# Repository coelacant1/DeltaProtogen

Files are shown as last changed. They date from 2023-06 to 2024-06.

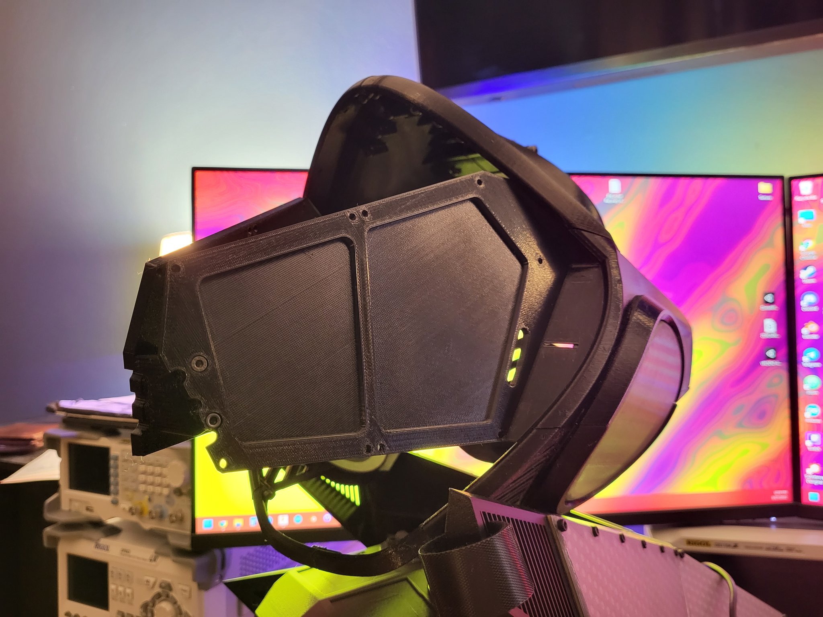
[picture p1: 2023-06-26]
Pictures/Print.jpg

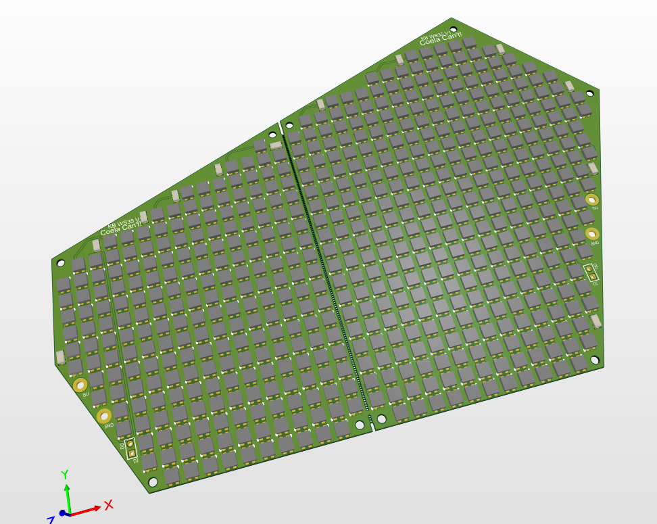
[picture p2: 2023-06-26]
Pictures/LEDBoard1.png

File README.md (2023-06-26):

# Delta Protogen

------------------------------------------
Coela Can't! Delta Protogen V1
Document Version: V1.0
------------------------------------------

Included are all of the STL files pre-oriented and ready for printing. But what about the visor? Well, two versions of the vacuum forming buck are included as well so you have the ability to make your own PETG visors. Don't forget that the 3D STEP and IGES CAD files are included, so if the design is not exactly what you want then you have the ability to modify and tweak it!

This design is built around printing on the Prusa i3 MK3s with build dimensions of X:250mm, Y:210mm, and Z:210mm. This design can be printed on smaller printers but may need to be modified or split requiring glue or the addition of screw mounts.

------------------------------------------
ASSEMBLY
------------------------------------------
Parts list:
Generic metric hardware kit (M3, M4, M5): https://www.amazon.com/Assortment-AETTL-Stainless-Assorted-Wrenches/dp/B098ND1GW8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
Threaded insert kit (M2, M3, M4, M5): https://www.amazon.com/DYWISHKEY-Knurled-Threaded-Embedment-Assortment/dp/B07MWBJB67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
M2 Screws (For Custom LED panels): https://www.amazon.com/uxcell-M2x6mm-Thread-Button-Socket/dp/B01B1OD9UQ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

The frame will bolt together with the use of M3 hardware, almost entirely with M3x8mm/10mm, ensure the screws are not protruding.
The top hinge is mounted with M5 threaded inserts and the hinge mechanism uses an M5 threaded insert and an M5x30mm bolt.
The rear latches are mounted with M3 threaded inserts and M3x10mm screws and use M5x8mm bolts with 20mm M5 grub screws.

------------------------------------------
VISOR
------------------------------------------
Print the V1 or V2 Buck
Make a vacuum former tutorial: https://www.youtube.com/watch?v=Gx66mS7U2vY
Material: Use 0.04" or 1.0mm PETG for proper thickness 

Magnetic mounts visor mount should be attached with a form of adhesive - double sided tape or epoxy - careful with super glue on the visor though! It will cloud it up. Use 6mmx2mm neodymium magnets and check the direction: https://www.amazon.com/FINDMAG-Refrigerator-Magnets-Premium-Whiteboard/dp/B075RZ82HP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

------------------------------------------
3D Printing
------------------------------------------
Recommended build dimensions: 250mmx210mmx210mm
Resolution: 0.2mm or higher quality
Supports: Depending on the overhang capabilities with your build plate, most require no support. The jaw requires a raft. Top head/forehead requires support.
Brim: Depending on your build surface a brim may be needed to bed adhesion
Material: PETG for frame and PVB for transparent side display covers - PLA can be used but it can melt if left in hot areas or in vehicles

------------------------------------------
Electronics for Custom LED Boards
------------------------------------------
Controller:
Teensy 4.0: https://www.pjrc.com/store/teensy40.html
OctoWS2811 LED Controller for the Teensy 4.0: https://www.pjrc.com/store/octo28_adaptor.html

Power: 
USB-C Decoy Trigger (USB-C to set voltage out): https://www.amazon.com/Type-C-USB-C-charge-trigger-detector/dp/B07T6LPP9W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
Buck Converter (5v-38V input to 5V output with at least 5 amps): https://www.amazon.com/Pololu-Step-Down-Voltage-Regulator-D24V90F5/dp/B01M9C9Q1E
Recommend 20W+ USB-C PD battery

Provide 5V directly to the LED boards from the buck converter and the signal lines from the OctoWS2811 controller.

------------------------------------------
Electronics for P3 Panels
------------------------------------------
Controller:
Teensy 4.0: https://www.pjrc.com/store/teensy40.html
SmartLED Shield for Teensy 4.0: https://www.crowdsupply.com/pixelmatix/smartled-shield-for-teensy-4

Power: 
USB-C Decoy Trigger (USB-C to set voltage out): https://www.amazon.com/Type-C-USB-C-charge-trigger-detector/dp/B07T6LPP9W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
Buck Converter (5v-38V input to 5V output with at least 5 amps): https://www.amazon.com/Pololu-Step-Down-Voltage-Regulator-D24V90F5/dp/B01M9C9Q1E
Recommend 20W+ USB-C PD battery

Provide 5V directly to the LED boards from the buck converter and the signal lines from the OctoWS2811 controller.

------------------------------------------
Software
------------------------------------------
Software for controlling the head can be found at: https://github.com/coelacant1/ProtoTracer
To use this with the custom LED boards, include the KaiborgV1D1Controller.h as the primary controller and pick the animation to display on the face from the animations class.
To use this with P3 HUB75 LED panels, include SmartMatrixHub75.h as the primary controller and pick the animation to display on the face from the animations class.

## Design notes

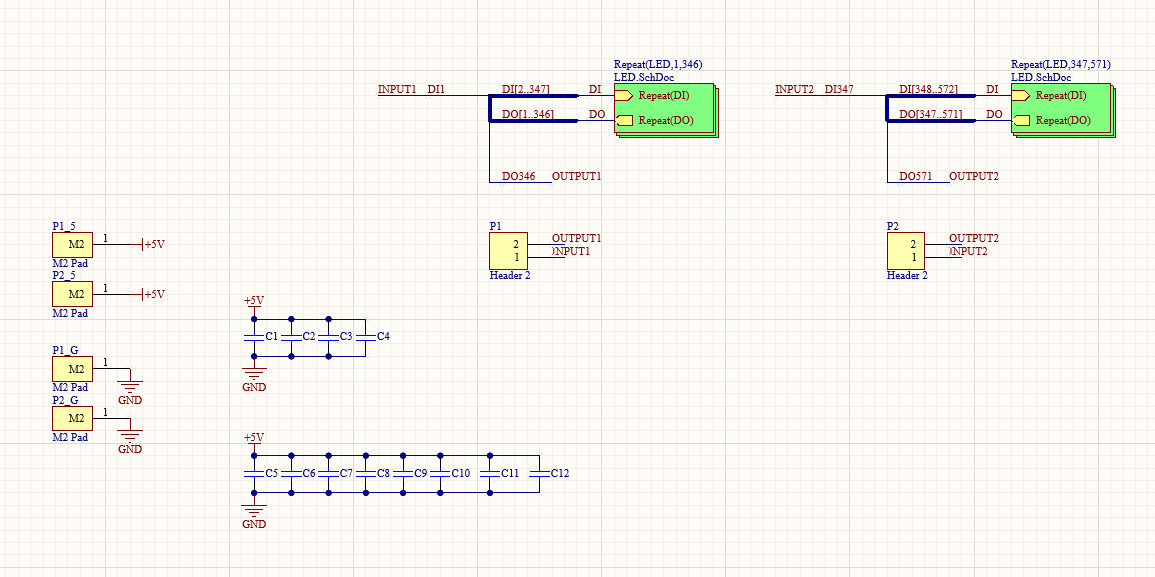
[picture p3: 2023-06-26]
Pictures/Schematic.png

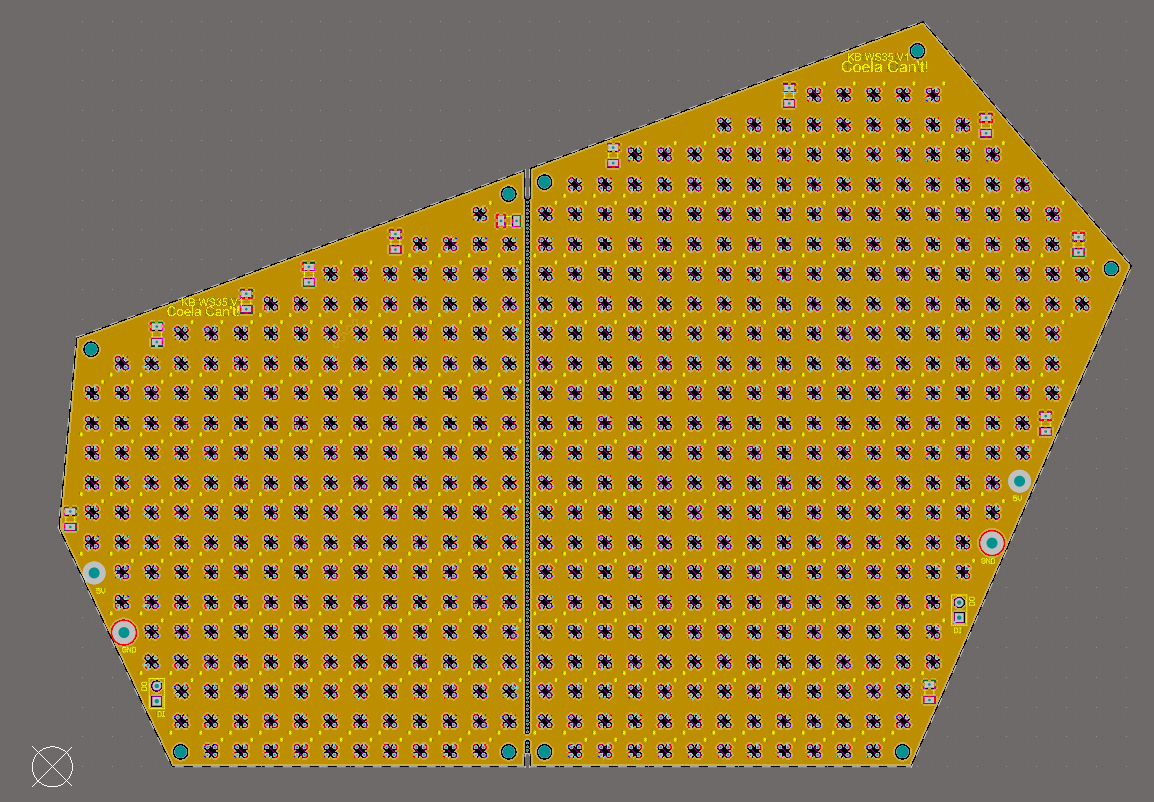
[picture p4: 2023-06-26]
Pictures/SignalLayer1.png

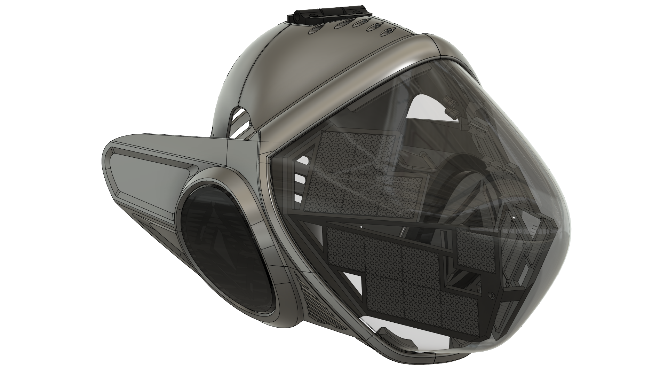
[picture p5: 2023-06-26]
Pictures/CoelaProtoSmoothV1_MAX7219.png

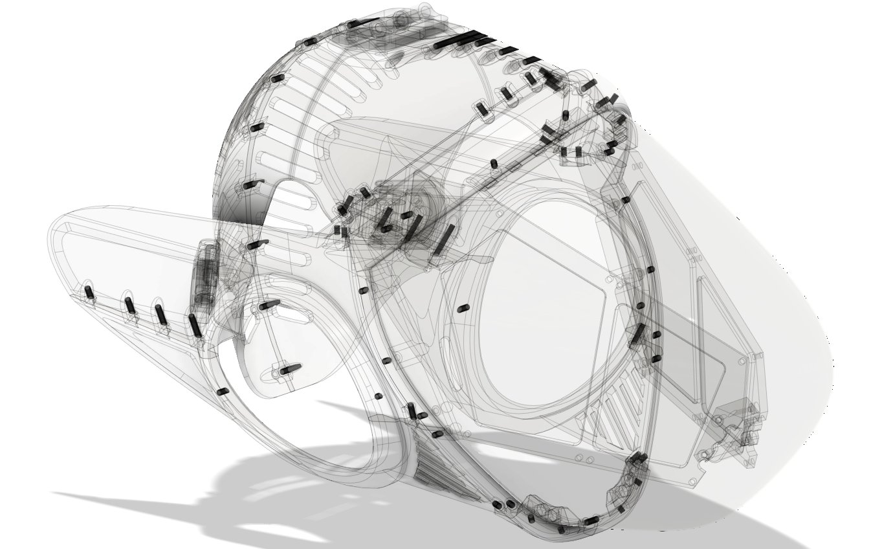
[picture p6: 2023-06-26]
Pictures/XRay.jpg

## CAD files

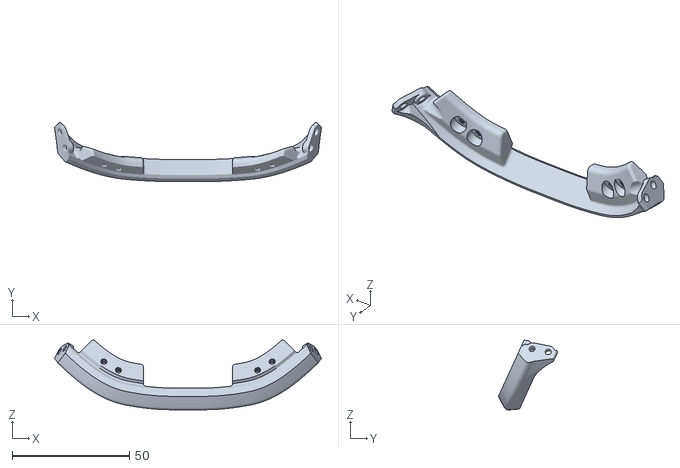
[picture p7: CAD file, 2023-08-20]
Frame/FullJaw.stl
113.7 x 25.2 x 29.7

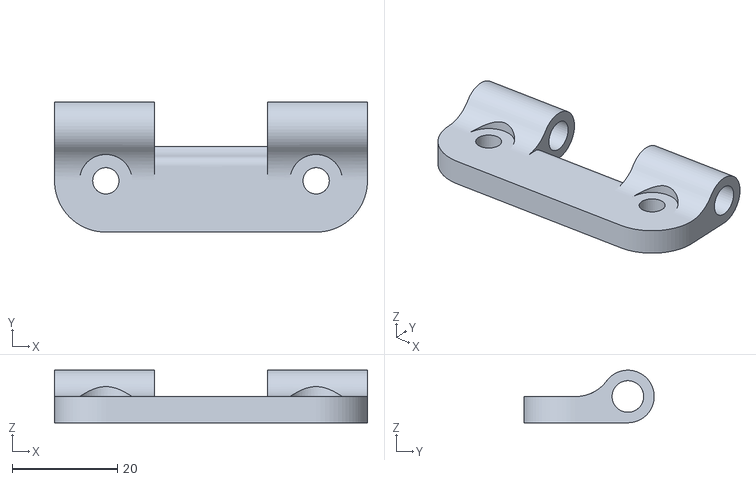
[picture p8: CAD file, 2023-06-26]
Hinge/FrontHinge_V1-0.stl
59.4 x 24.8 x 10.00

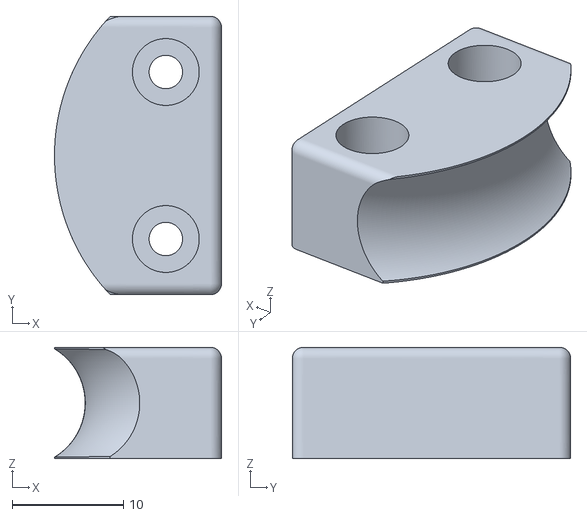
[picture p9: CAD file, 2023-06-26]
Latch/LatchLeftMount_V1-0.stl
15.0 x 25.0 x 10.0

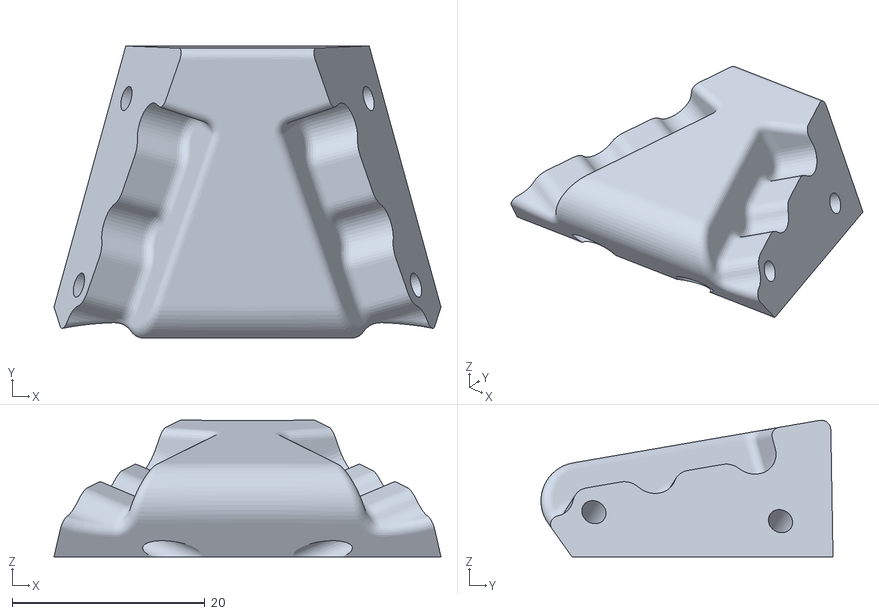
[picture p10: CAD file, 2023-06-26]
LED Mount KS W35/KSWS35_Connector_V1-0.stl
40.2 x 30.3 x 14.2

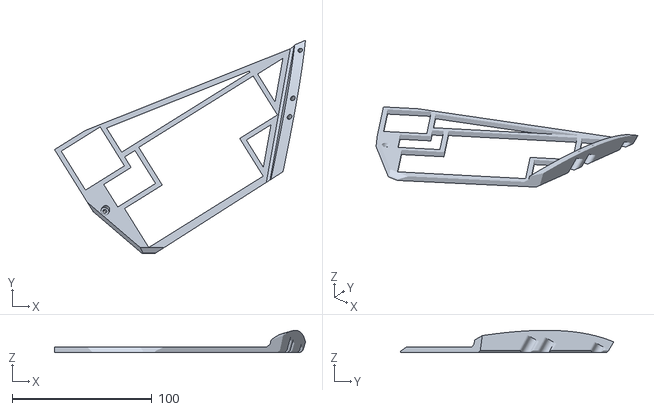
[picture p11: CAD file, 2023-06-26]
LED Mount MAX7219/MAX7219BotLeft_V1-0.stl
179.5 x 152.7 x 16.0

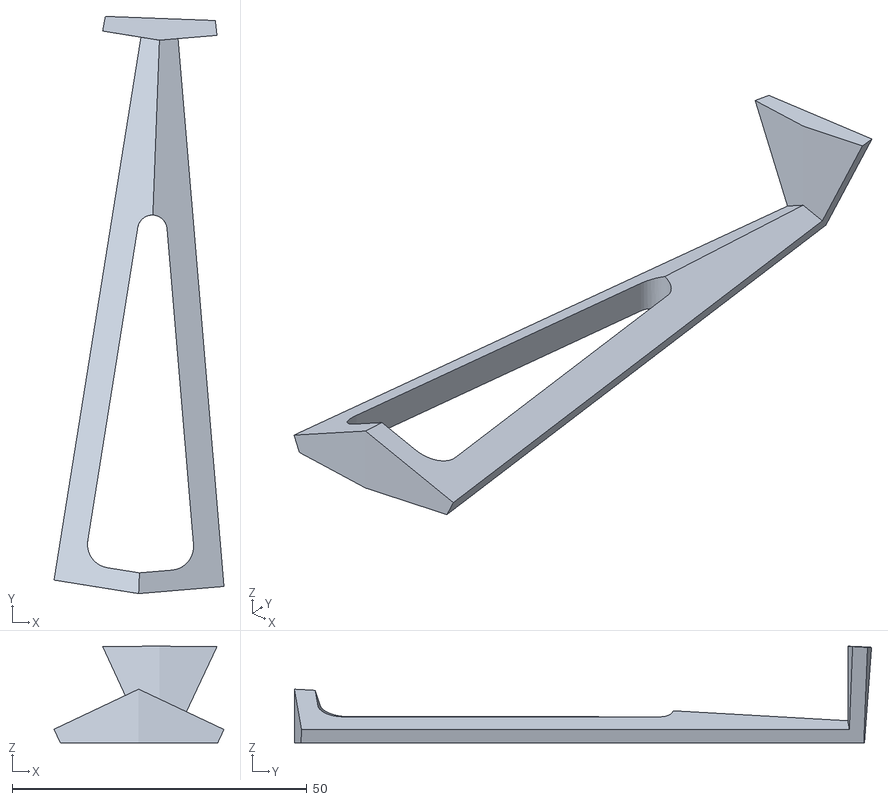
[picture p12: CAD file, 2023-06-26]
LED Mount P3 HUB75/P3Nose_V1-0.stl
28.9 x 98.0 x 16.4

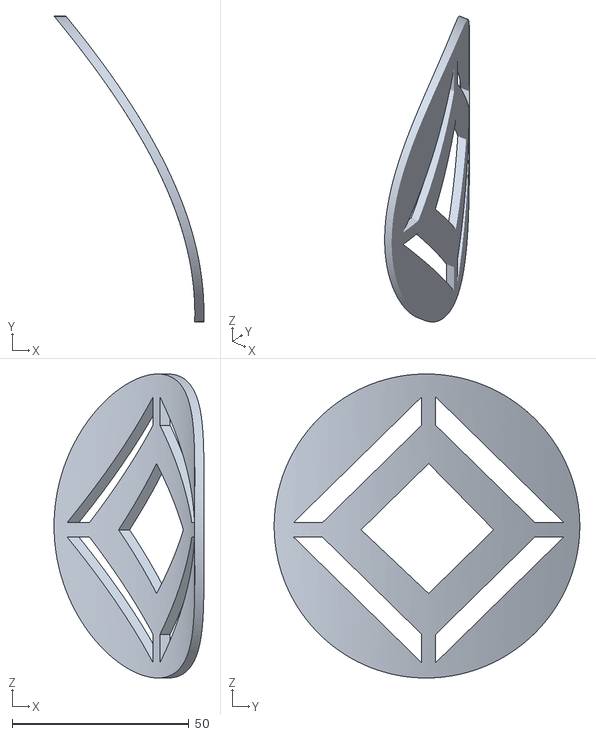
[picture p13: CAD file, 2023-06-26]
Side Displays/LeftPuckInnerSample_V1-0.stl
42.4 x 86.5 x 86.0

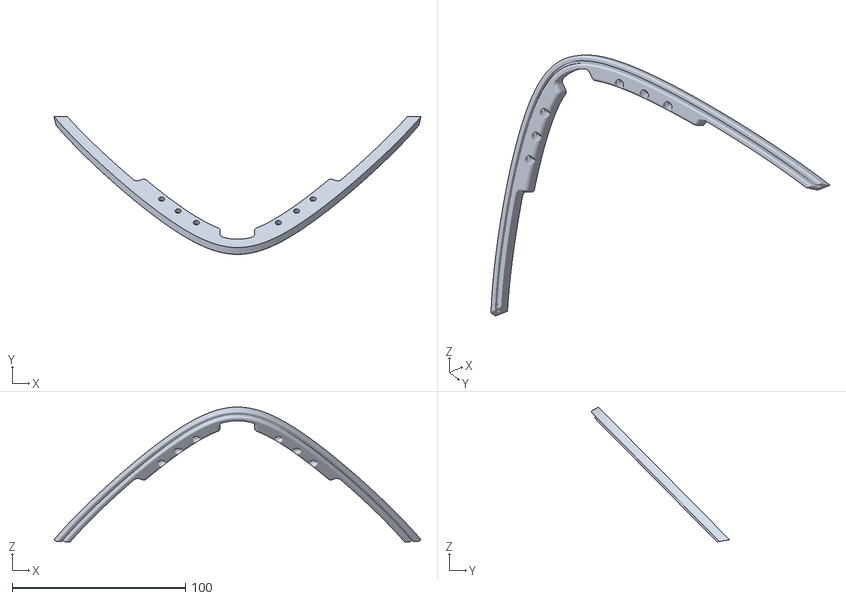
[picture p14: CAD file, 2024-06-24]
Visor Mounts/VisorSupportTopCover.stl
212.1 x 79.6 x 77.9

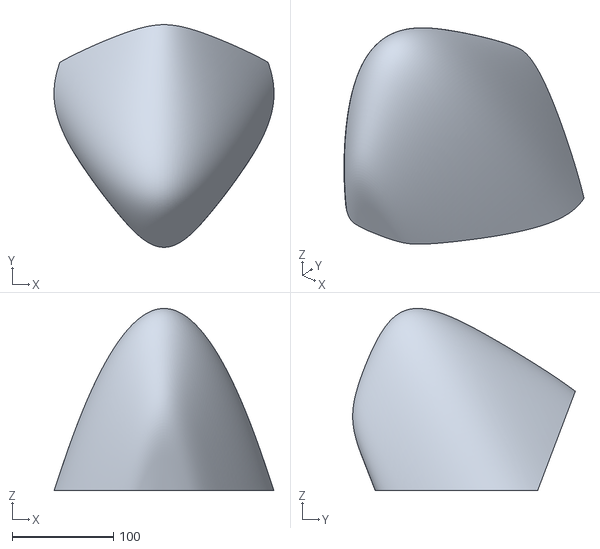
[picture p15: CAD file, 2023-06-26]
Visor/Visor_V1-0.stl
216.9 x 219.5 x 179.5

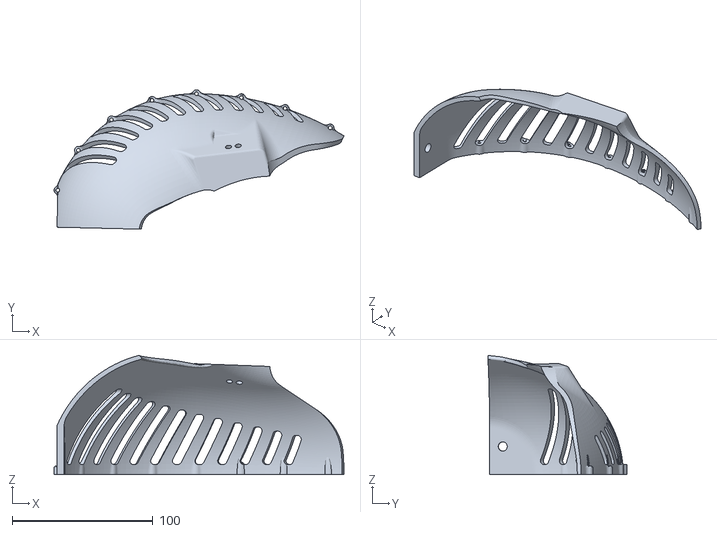
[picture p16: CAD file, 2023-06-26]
Frame/LeftBackHelmet_V1-0.stl
206.4 x 99.2 x 84.9

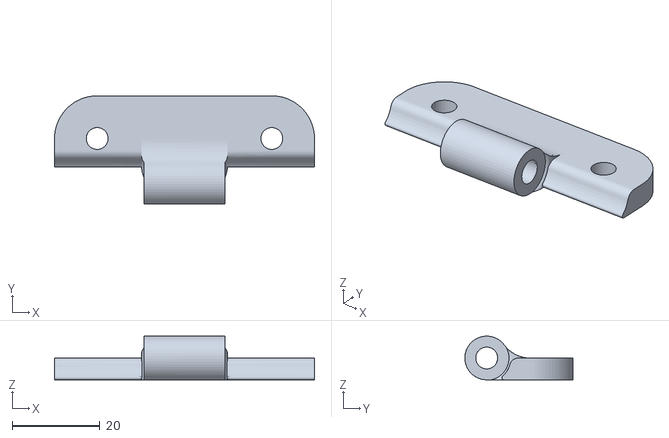
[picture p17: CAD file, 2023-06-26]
Hinge/BackHinge_V1-0.stl
59.4 x 24.8 x 10.00

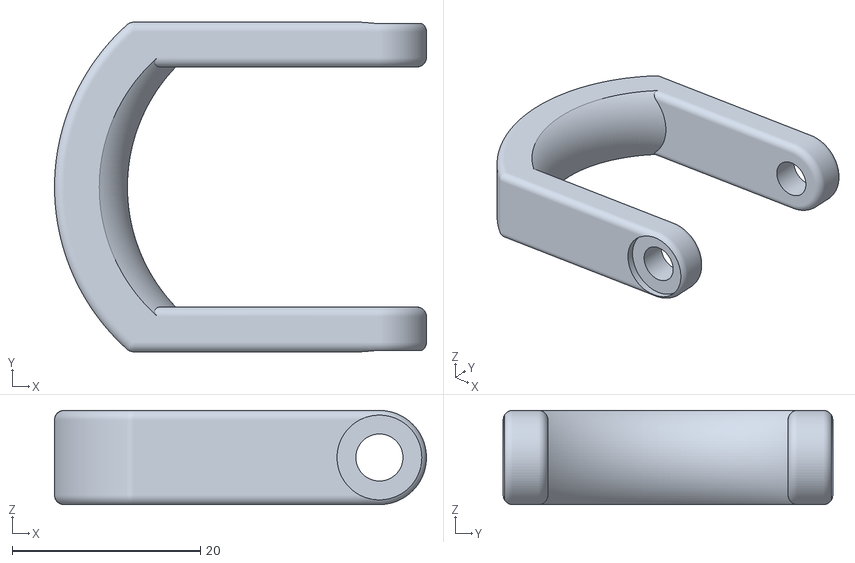
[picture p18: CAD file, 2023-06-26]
Latch/LatchOuterRotate_V1-0.stl
39.5 x 35.0 x 10.0

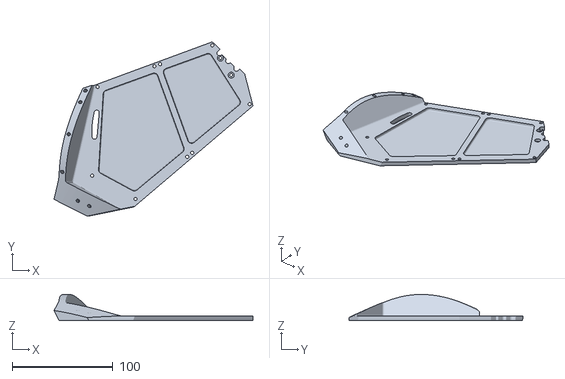
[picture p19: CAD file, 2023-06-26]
LED Mount KS W35/KSWS35_Left_V1-0.stl
197.3 x 172.9 x 25.8

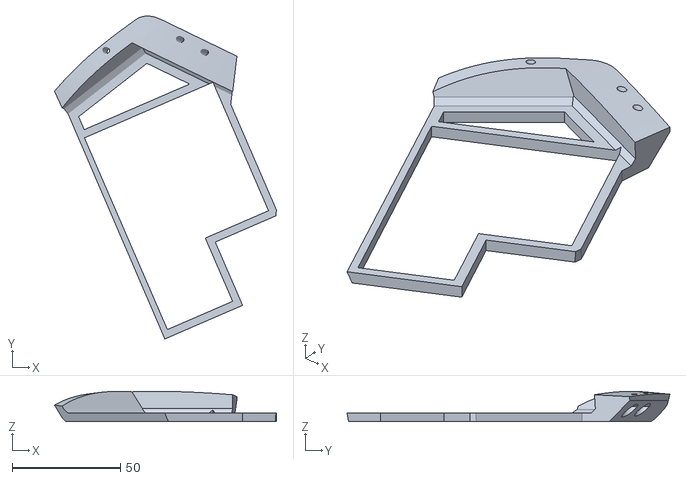
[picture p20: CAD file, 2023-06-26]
LED Mount MAX7219/MAX7219TopRight_V1-0.stl
102.4 x 149.0 x 14.0

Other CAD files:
Sliced P1X/DeltaPrint_VisorMounts.gcode.3mf
LED Mount P3 HUB75/P3LeftMount_V1-0.stl
Side Displays/LeftPuck_V1-0.stl
Sliced P1X/DeltaPrint_HUB75Face.gcode.3mf
Frame/LeftBackMid_V1-0.stl
Frame/LeftBottom_V1-0.stl
Frame/LeftJaw_V1-0.stl
Frame/RightBackHelmet_V1-0.stl
Frame/RightBackMid_V1-0.stl
Frame/RightBottom_V1-0.stl
Frame/RightHead_V1-0.stl
Frame/RightJaw_V1-0.stl
Frame/TopLeftForehead_V1-0.stl
Frame/TopRightForehead_V1-0.stl
LED Mount KS W35/KSWS35_Right_V1-0.stl
LED Mount MAX7219/MAX7219BotRight_V1-0.stl
LED Mount MAX7219/MAX7219Connector_V1-0.stl
LED Mount MAX7219/MAX7219TopLeft_V1-0.stl
LED Mount P3 HUB75/P3RightMount_V1-0.stl
Latch/LatchInnerRotate_V1-0.stl
Latch/LatchOuterRotateWider_V1-0.stl
Latch/LatchRightMount_V1-0.stl
Side Displays/LeftPuckInner_V1-0.stl
Side Displays/RightPuckInnerSample_V1-0.stl
Side Displays/RightPuckInner_V1-0.stl
Side Displays/RightPuck_V1-0.stl
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

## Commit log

2023-06-26 Initial File Upload
    [BackHinge_V1-0.stl, BottomLeftInner_V1-1.stl, BottomLeftOuter_V1-1.stl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]
2023-08-20 Added visor support/Sliced files
    [BottomLeftOuter_V1-1.stl, BottomRightOuter_V1-1.stl, DeltaPrint_HUB75Face.gcode.3mf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]
2024-06-24 Updated visor supports
    [VisorSupportBottomCover.stl, VisorSupportTopCover.stl]
